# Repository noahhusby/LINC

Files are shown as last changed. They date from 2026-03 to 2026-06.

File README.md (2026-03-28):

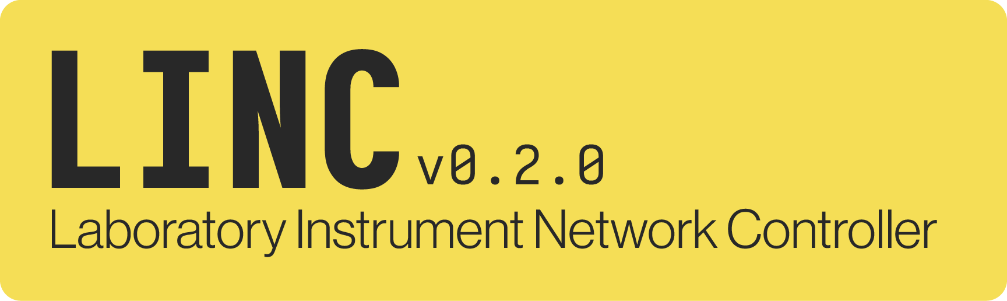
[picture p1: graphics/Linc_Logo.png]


## About

This project came about from the need to control my PM2812 dual-channel power supply manufactured by the Phillips and Fluke consortium in the mid 90s. While later revisions of this device did feature a serial port, the earlier versions (such as mine) were stuck with the GPIB/HP-IP interface. This interface was used on test equipment up until the mid 2010s and yet there is no simple or affordable way to communicate with it. The interface chips for GPIB are no longer manufactured and difficult to source. 

The goal of this project is to create a controller that can translate commands from a networked device (either over LAN or RS485) to the PM2812 power supply. This would allow for a desk-mounted control panel with a modern OLED display and tactile controls to replace the dated "system power supply-type" interface found on the PM2812.

## Features

- Console Control 💾
  - Virtual COM port allows direct control of test equipment over integrated USB-C port
- Modern Hardware 💻
  - Based upon STM32H533 using new level shifters instead of legacy/unavailable SN7515x series chips
- Remote Control Capability 🛜
  - Integrated RS485 port for secondary physical control panel 

## Related

- LeHuman/[PMPi](https://github.com/LeHuman/PMPi)
- mnemocron/[gpibusb-firmware-stm32](https://github.com/mnemocron/gpibusb-firmware-stm32)

## License

This project is licensed under the `CERN OHL-P-v2 License`.

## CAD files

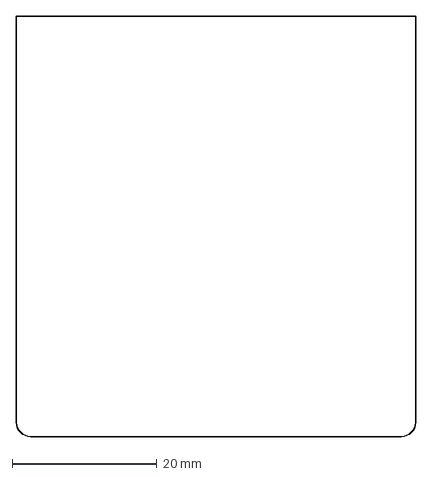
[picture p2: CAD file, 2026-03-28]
board_layout.dxf
55.1 x 58.0 mm

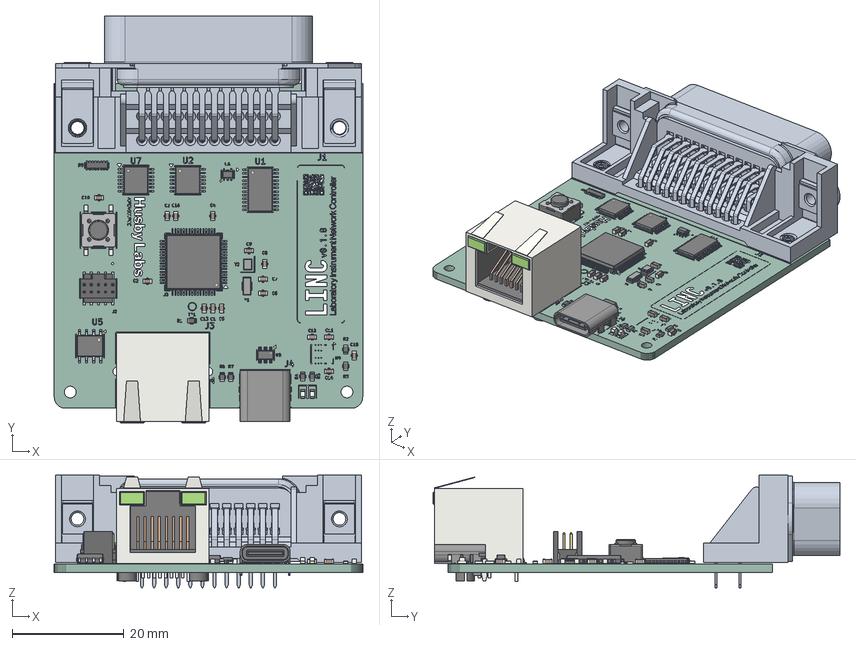
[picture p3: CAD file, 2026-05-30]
outputs/pcb/.step
55.1 x 72.7 x 20.1 mm
C_0603_1608Metric x 16
USB_C_Receptacle_GCT_USB4085
LQFP-64_10x10mm_P0.5mm
TSSOP-24_4.4x7.8mm_P0.65mm
SOIC-8_3.9x4.9mm_P1.27mm
LED_0603_1608Metric x 2
Crystal_SMD_2016-4Pin_2.0x1.6mm
TSSOP-14_4.4x5mm_P0.65mm x 2
R_0603_1608Metric x 7
SOT-23-6
112-024-113R001
SOT-353_SC-70-5
R_Array_Convex_8x0602
Crystal_SMD_3215-2Pin_3.2x1.5mm
RJ45_Amphenol_RJHSE538x
SW_SPST_PTS645Sx43SMTR92
FTSH-105-01-L-DV-K_body
FTSH-105-01-L-DV-K_pins1
FTSH-105-01-L-DV-K_pins2
LINC_silkscreen x 2
LINC_PCB

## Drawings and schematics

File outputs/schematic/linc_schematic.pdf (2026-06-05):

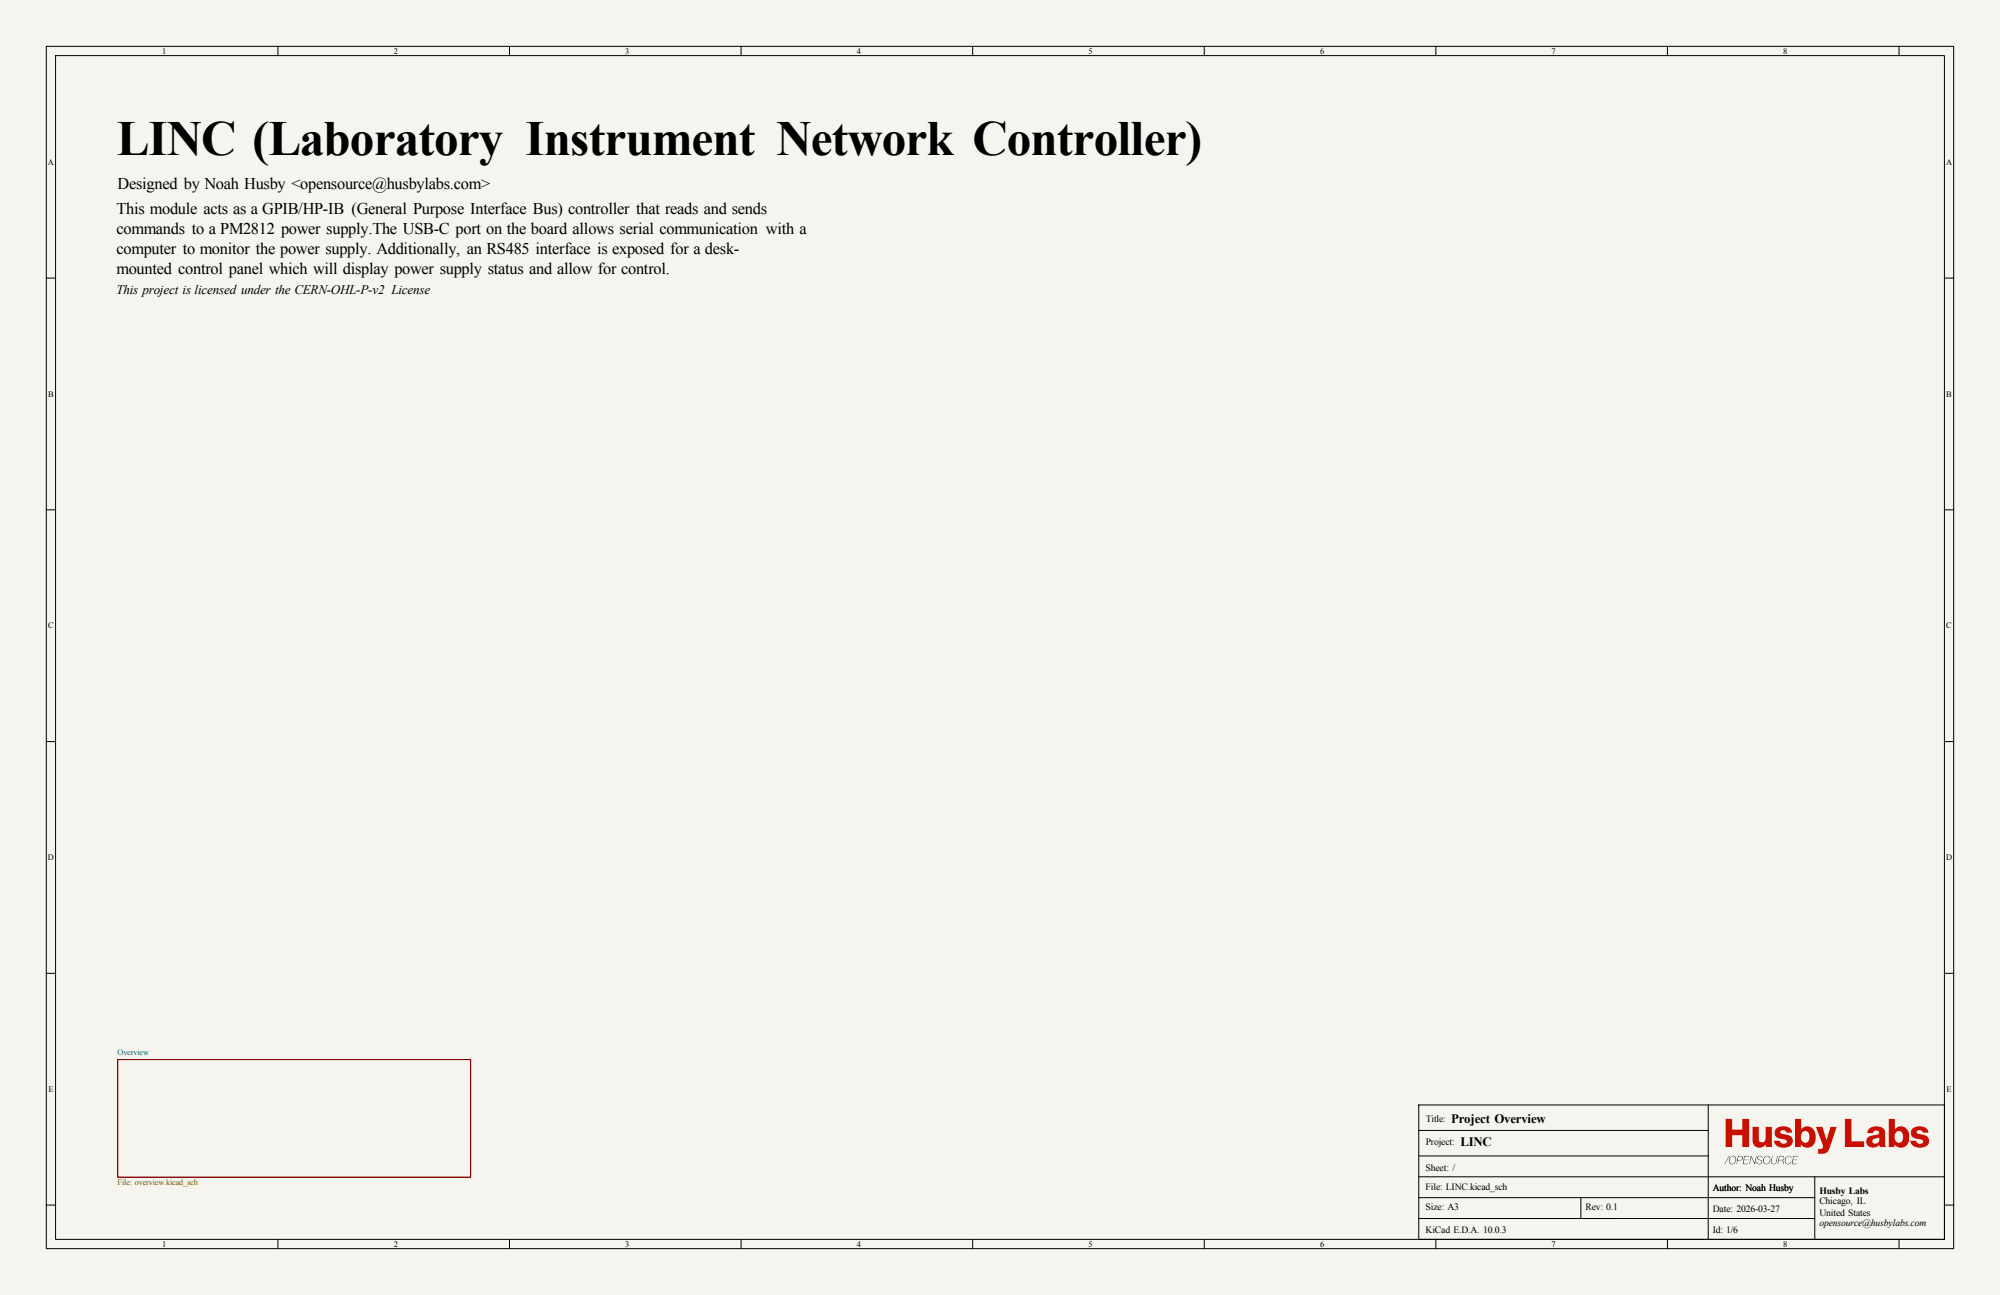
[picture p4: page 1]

LINC (Laboratory Instrument Network Controller)

Designed by Noah Husby <opensource@husbylabs.com>
This module acts as a GPIB/HP-IB (General Purpose Interface Bus) controller that reads and sends
commands to a PM2812 power supply.The USB-C port on the board allows serial communication with a
computer to monitor the power supply. Additionally, an RS485 interface is exposed for a desk-
mounted control panel which will display power supply status and allow for control.
This project is licensed under the CERN-OHL-P-v2 License

Id: 1/6 File: LINC.kicad_sch Sheet: / Project: LINC

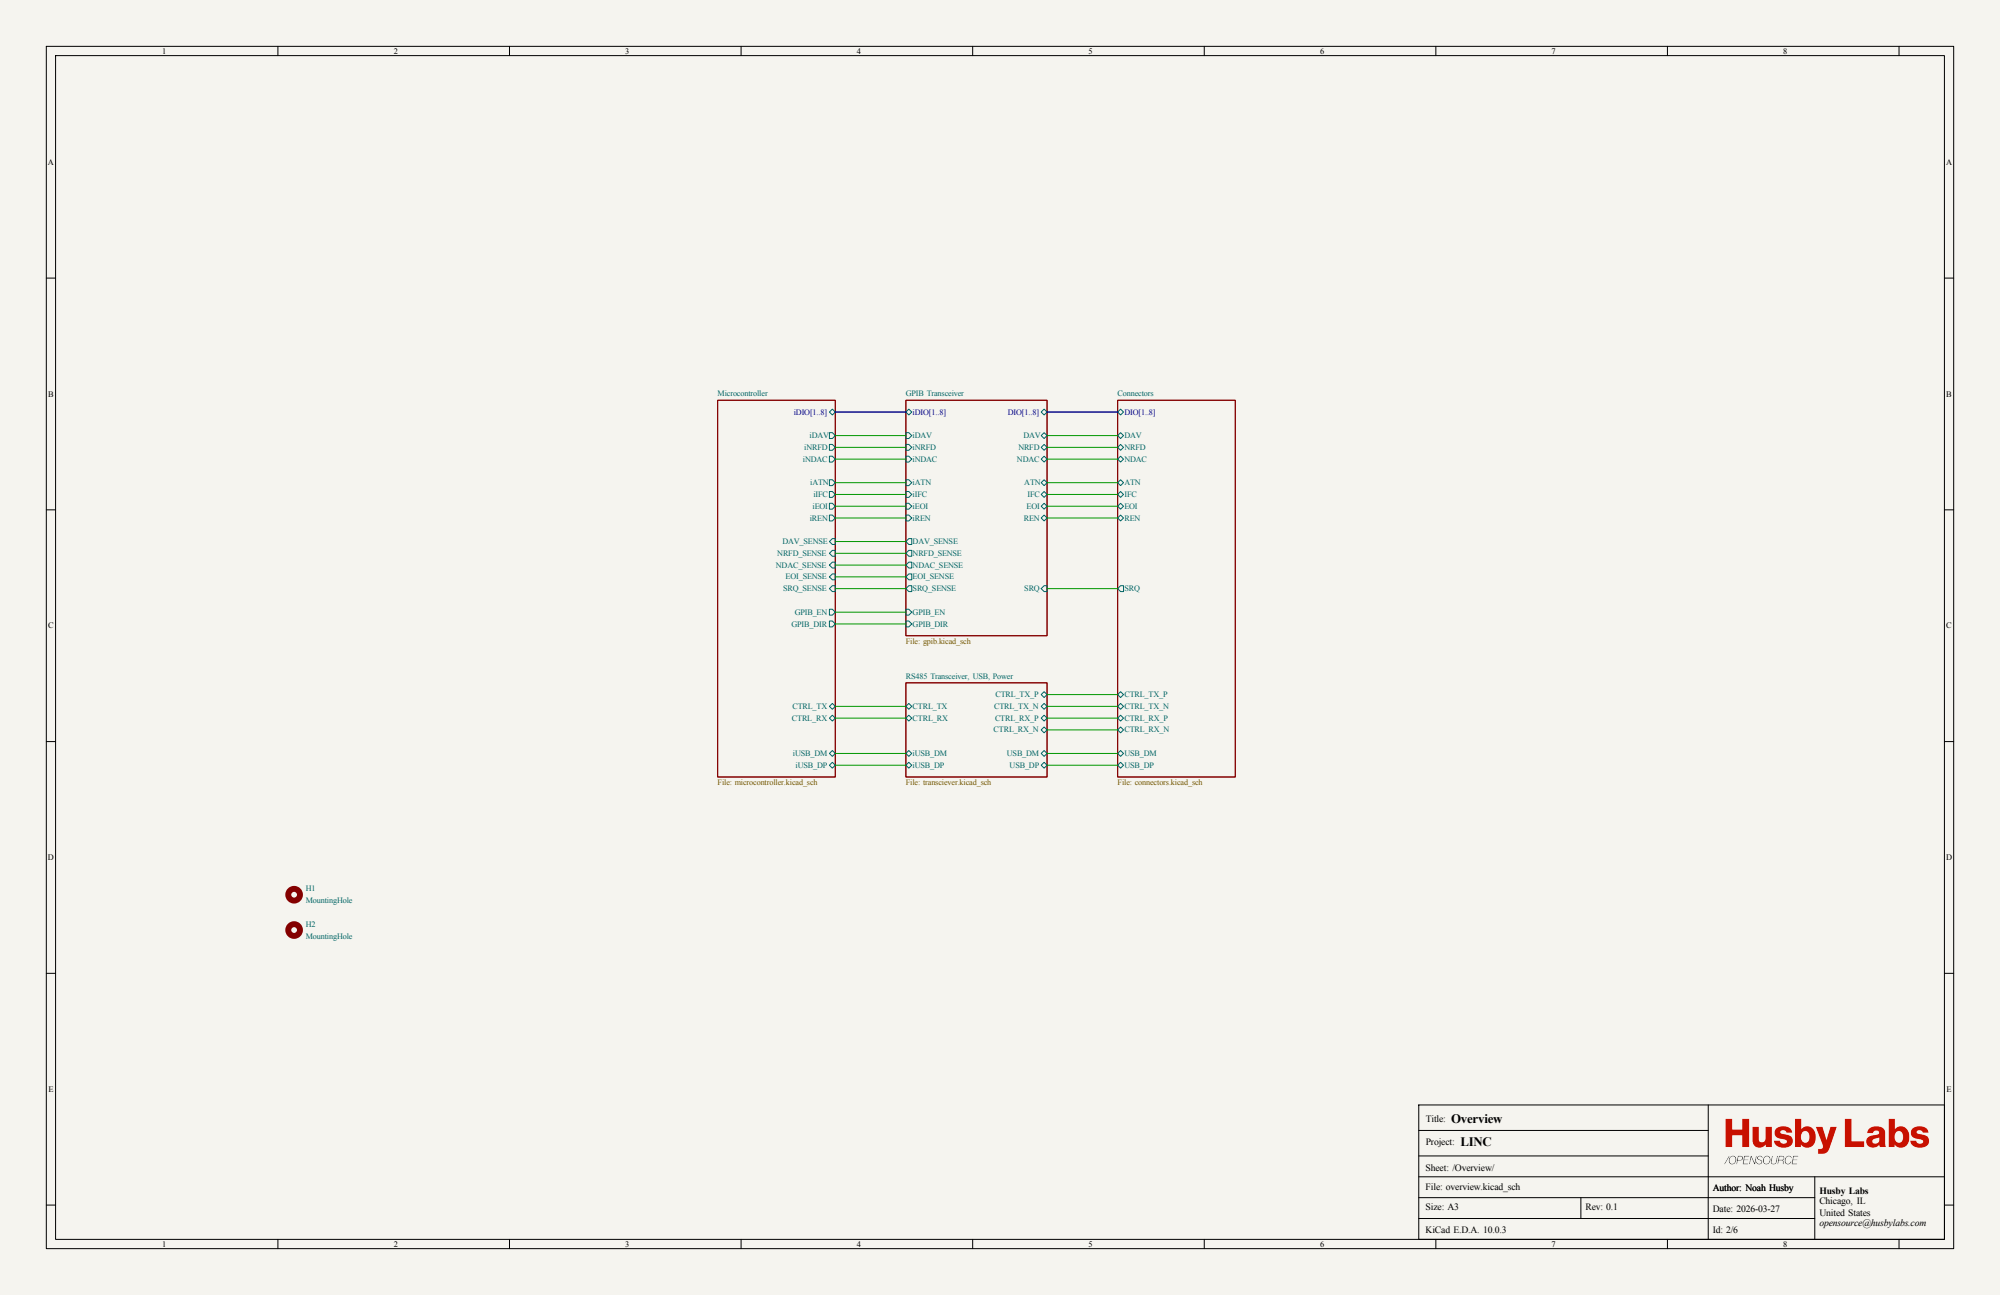
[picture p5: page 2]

iDIO[1..8] Microcontroller File: microcontroller.kicad_sch

USB_DP DIO[1..8] Connectors File: connectors.kicad_sch

iUSB_DP RS485 Transceiver, USB, Power File: transciever.kicad_sch H2 MountingHole H1 MountingHole

Id: 2/6 File: overview.kicad_sch Sheet: /Overview/ Project: LINC

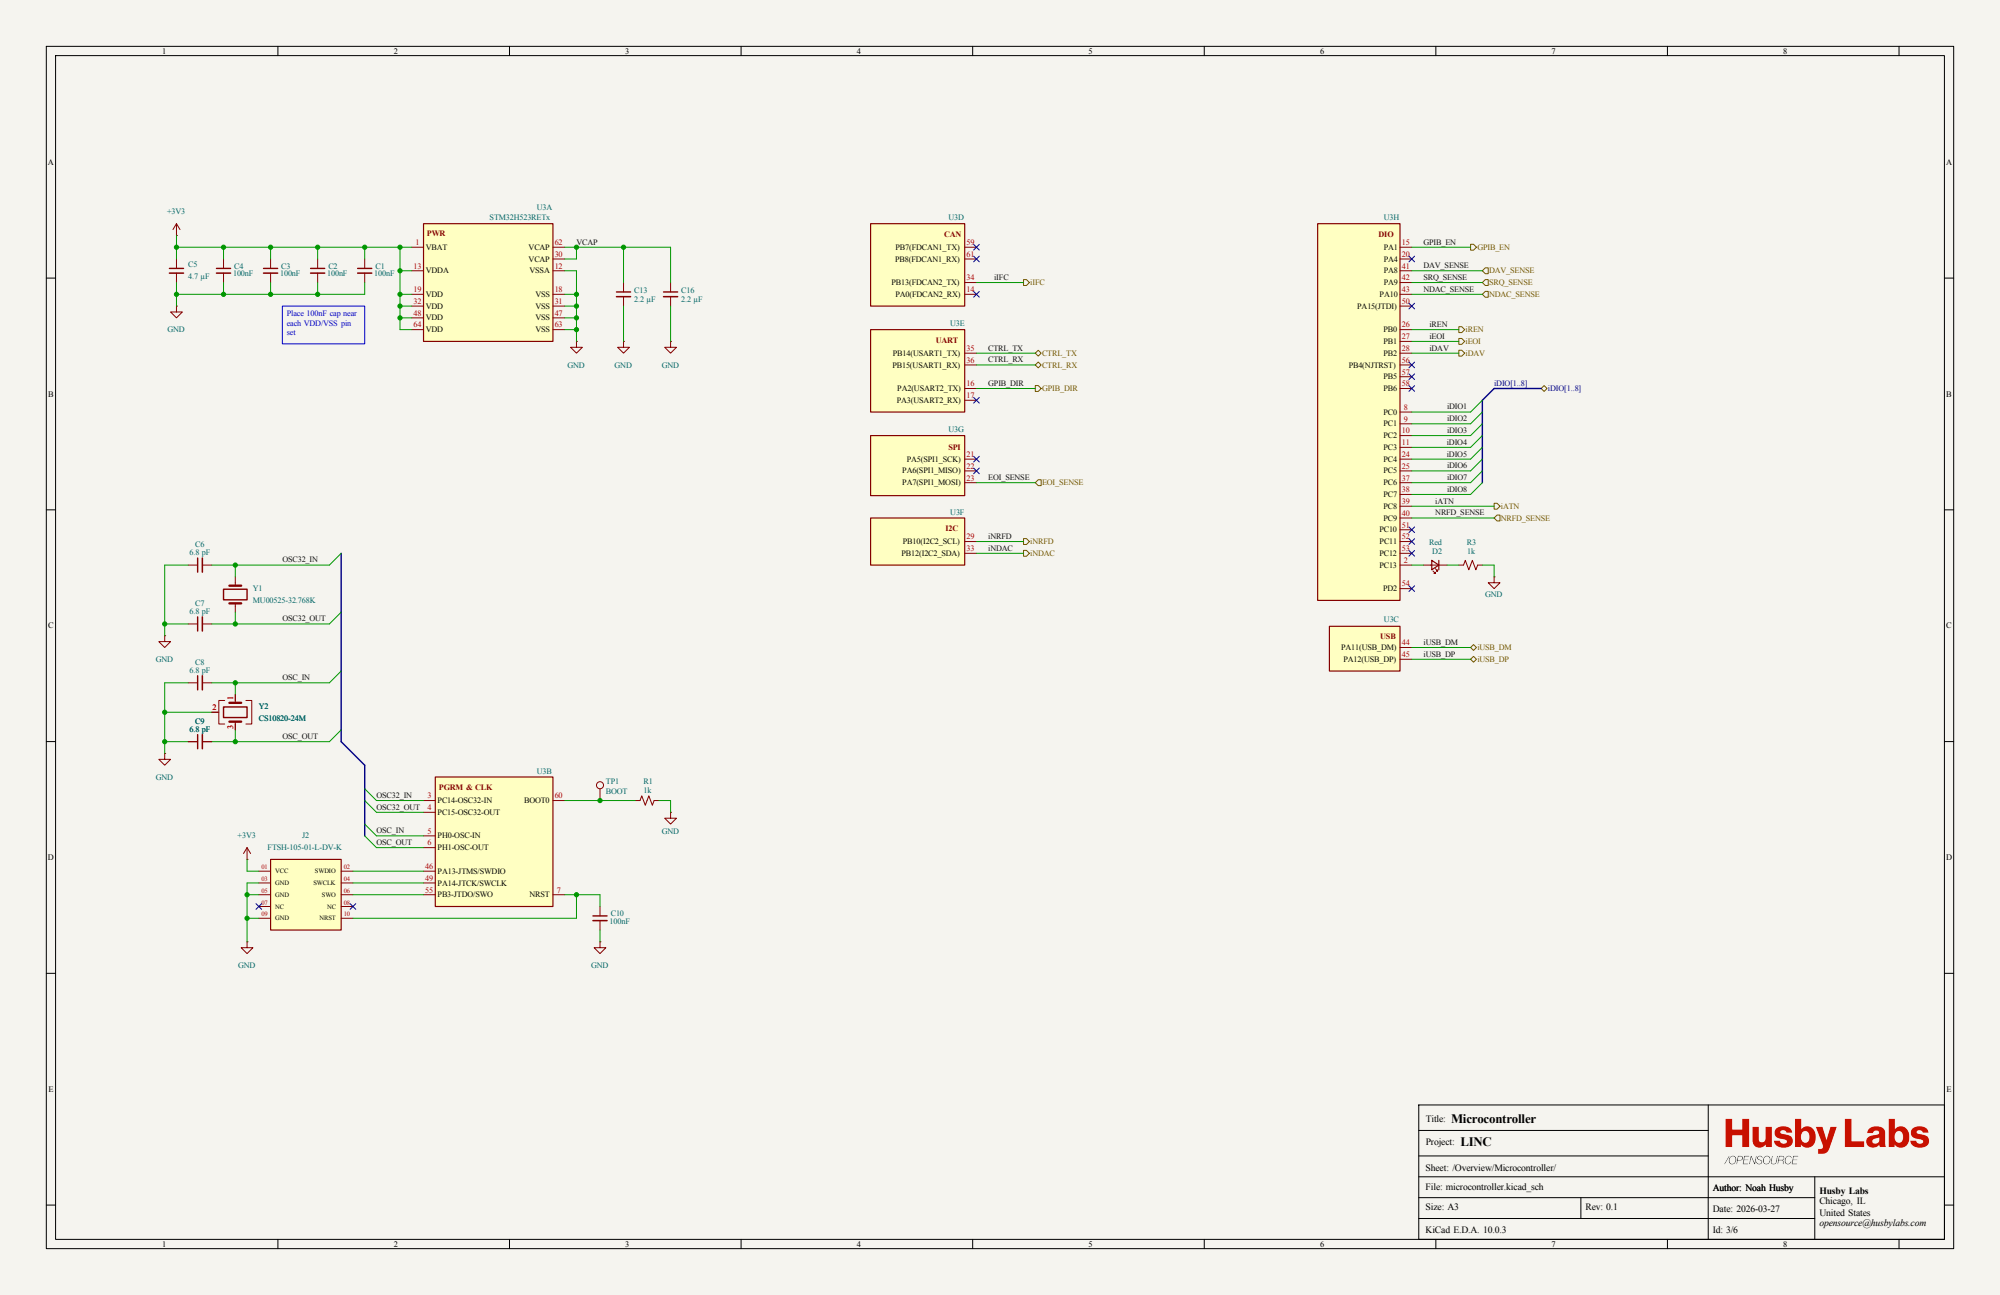
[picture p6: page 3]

Place 100nF cap near each VDD/VSS pin

Id: 3/6 File: microcontroller.kicad_sch Sheet: /Overview/Microcontroller/ Project: LINC

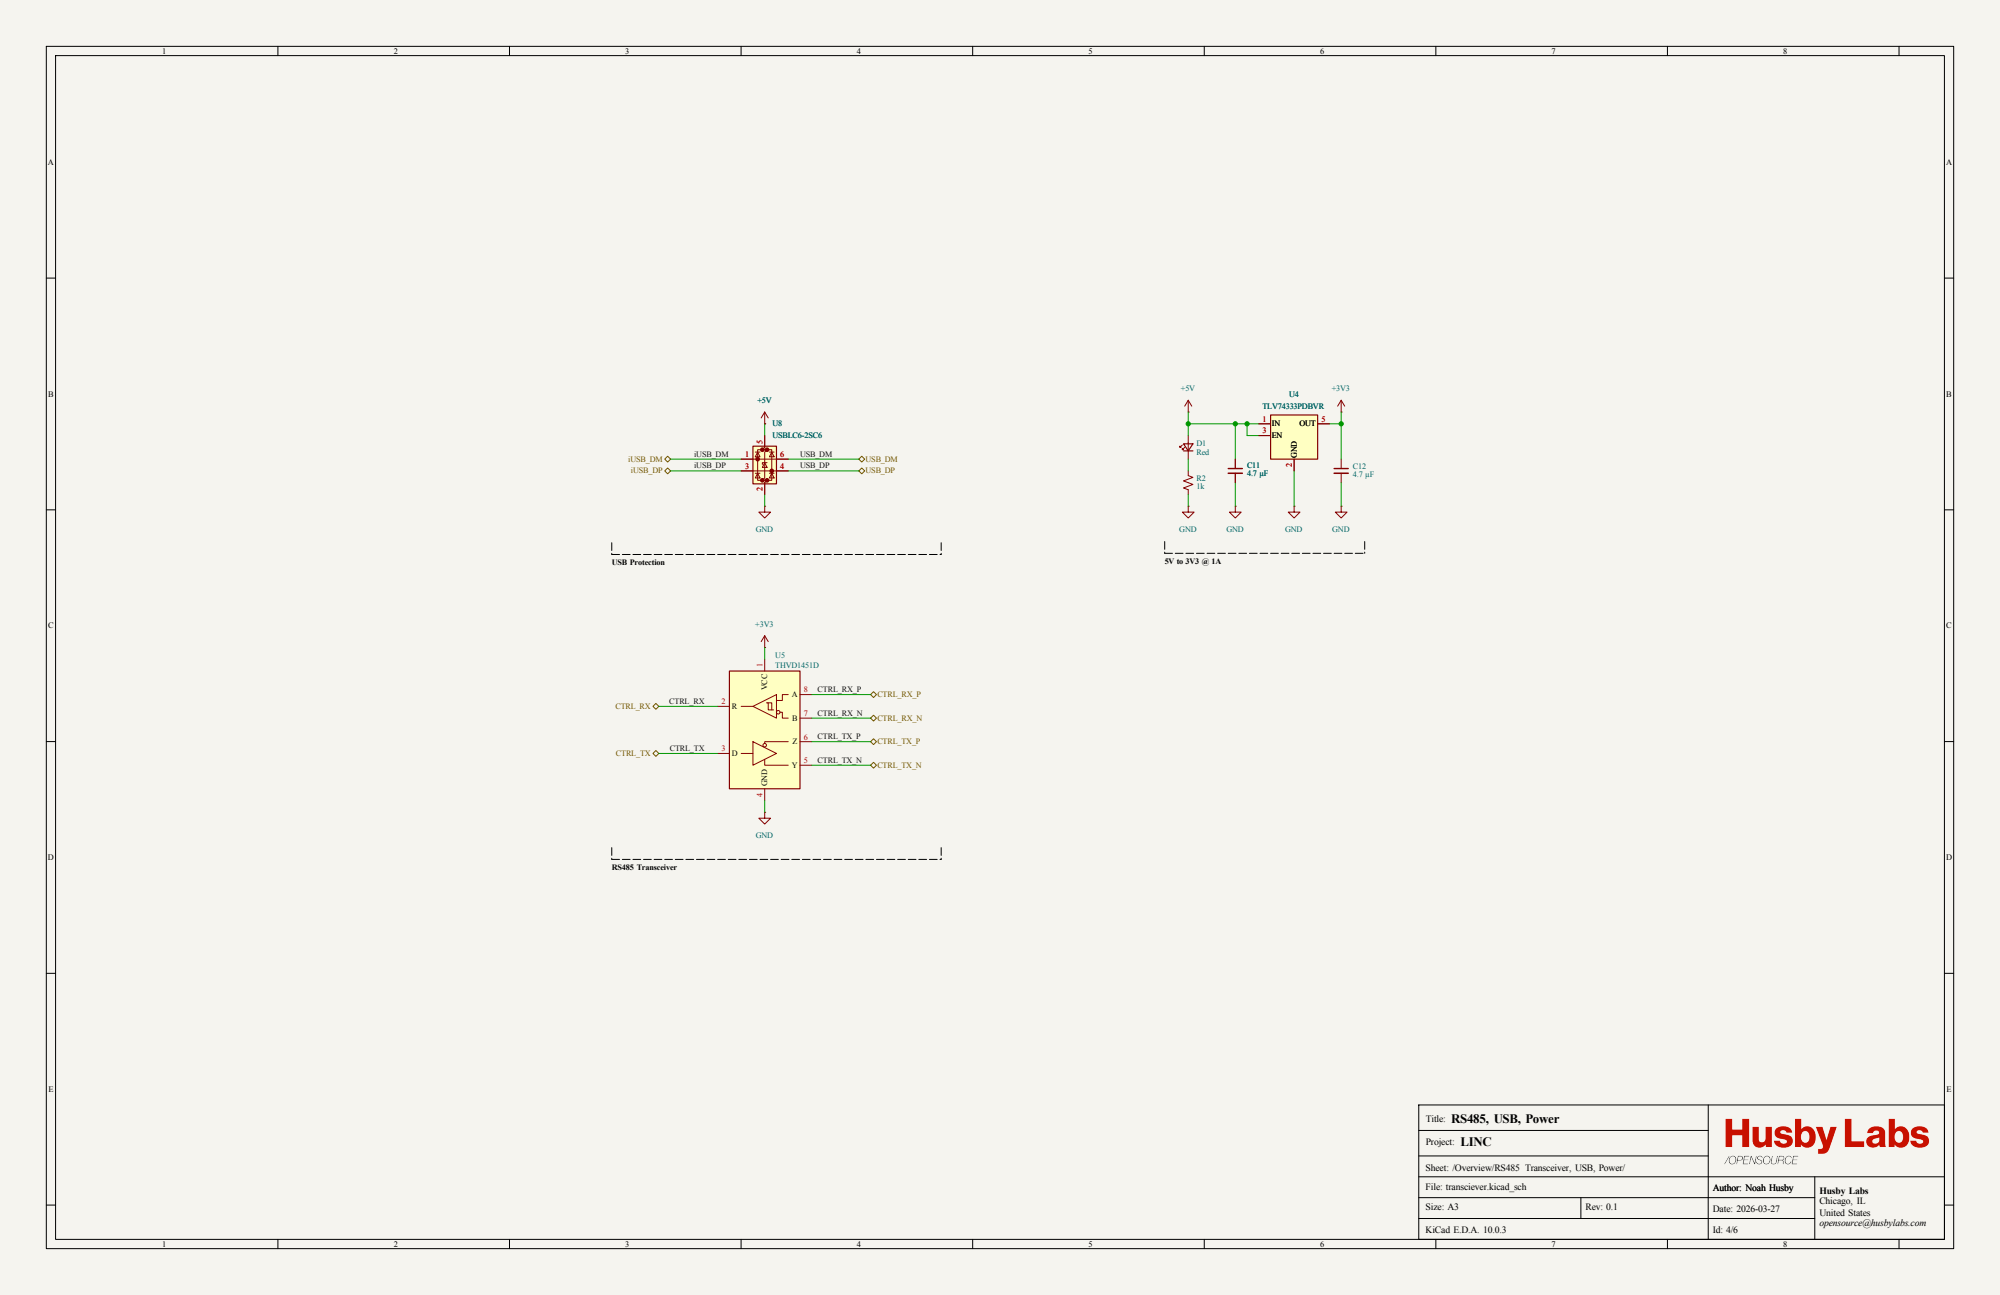
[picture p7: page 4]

Id: 4/6 File: transciever.kicad_sch Sheet: /Overview/RS485 Transceiver, USB, Power/ Project: LINC

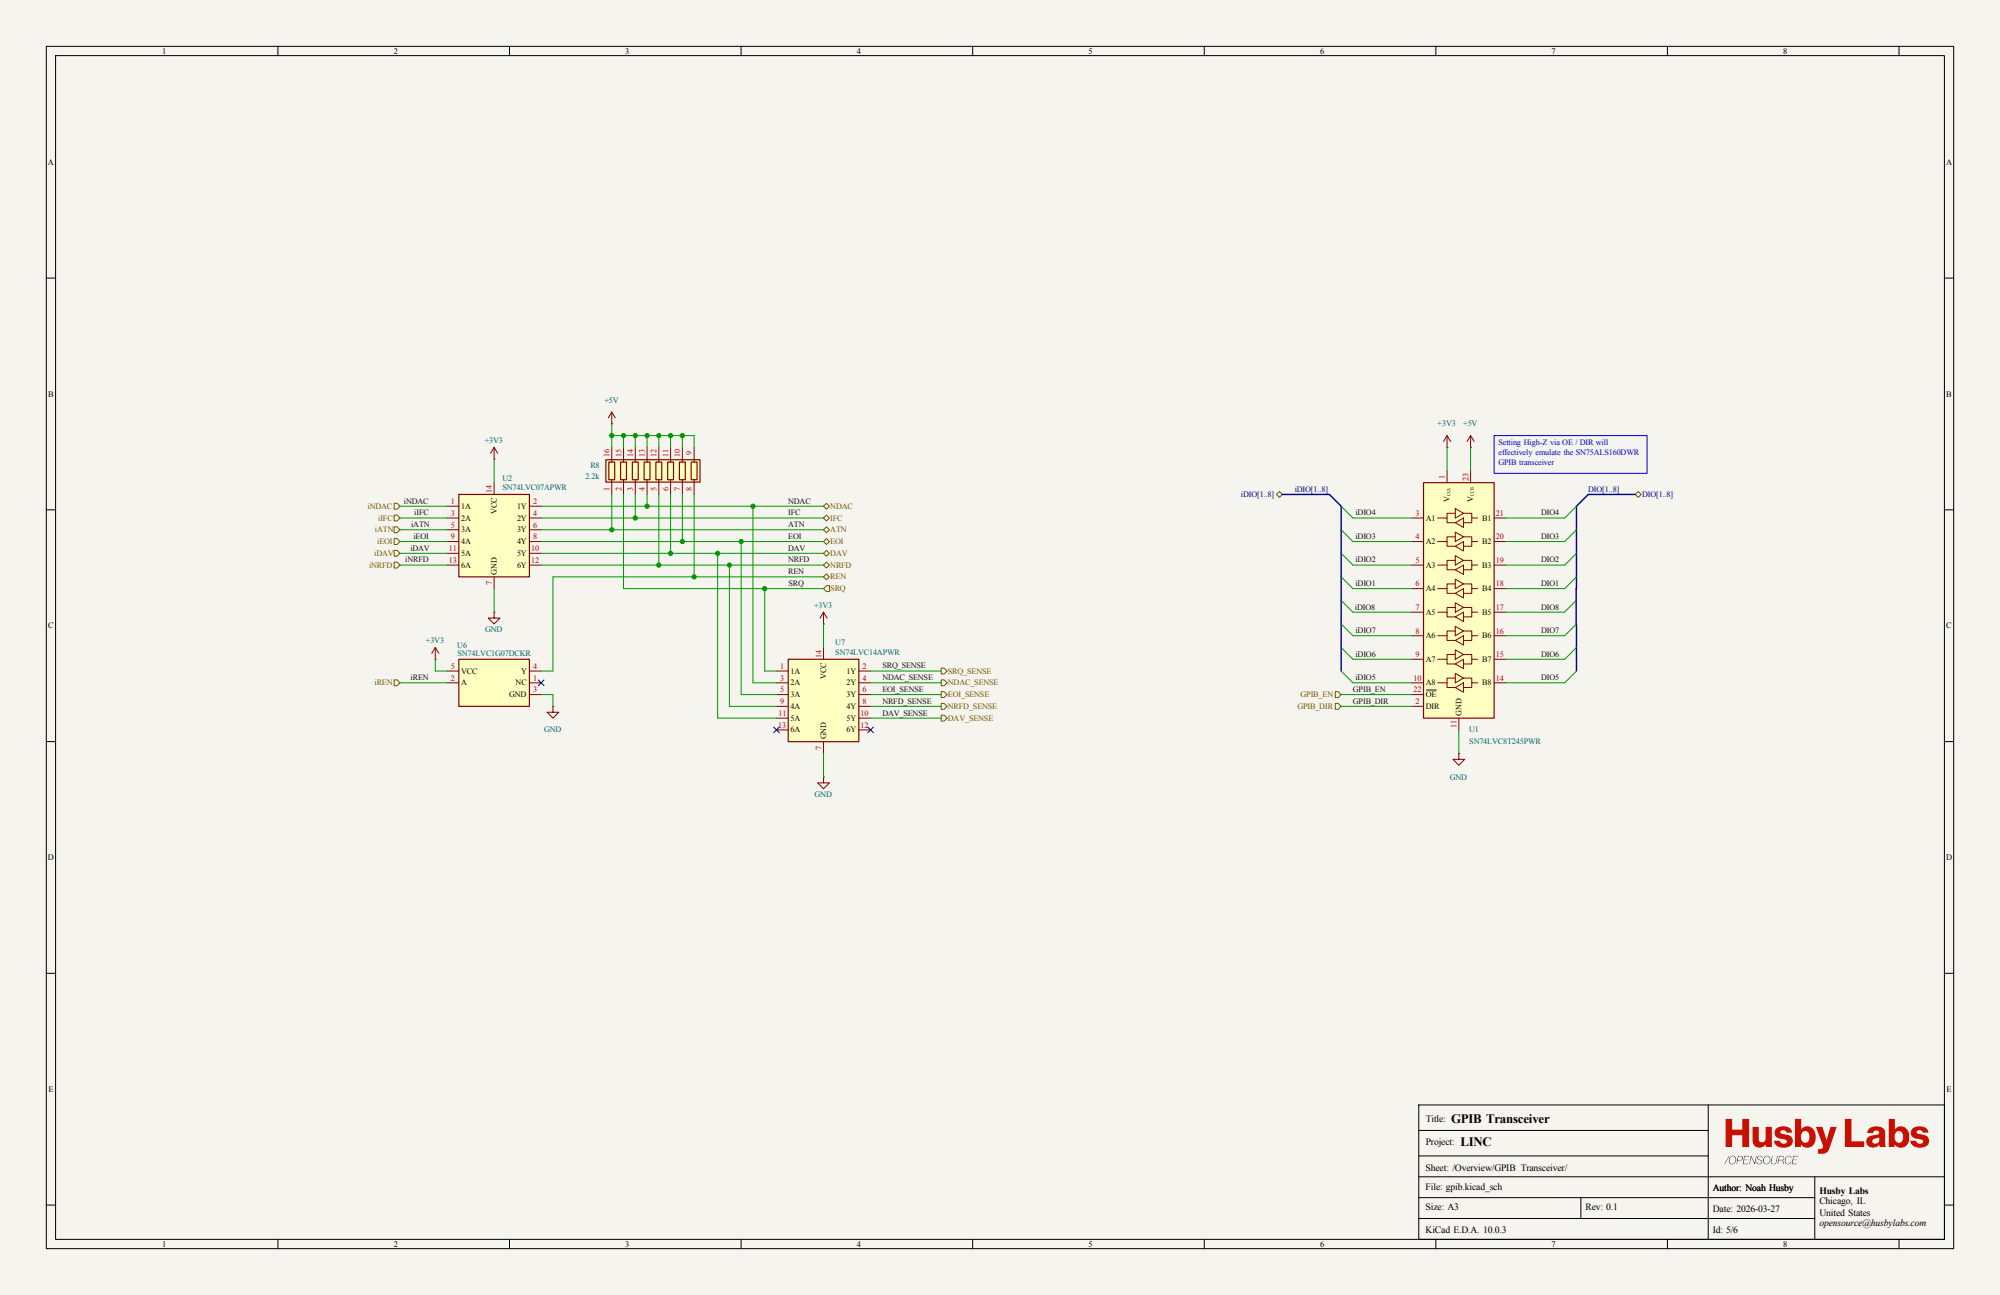
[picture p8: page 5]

VCCA 1 DIR 2 A1 3 A2 4 A3 5 A4 6 A5 7 A6 8 A7 9 A8 10 GND 11 B8 14 B7 15 B6 16 B5 17 B4 18 B3 19 B2 20 B1 21 OE 22 VCCB 23 U1 SN74LVC8T245PWR GND

Id: 5/6 File: gpib.kicad_sch Sheet: /Overview/GPIB Transceiver/ Project: LINC

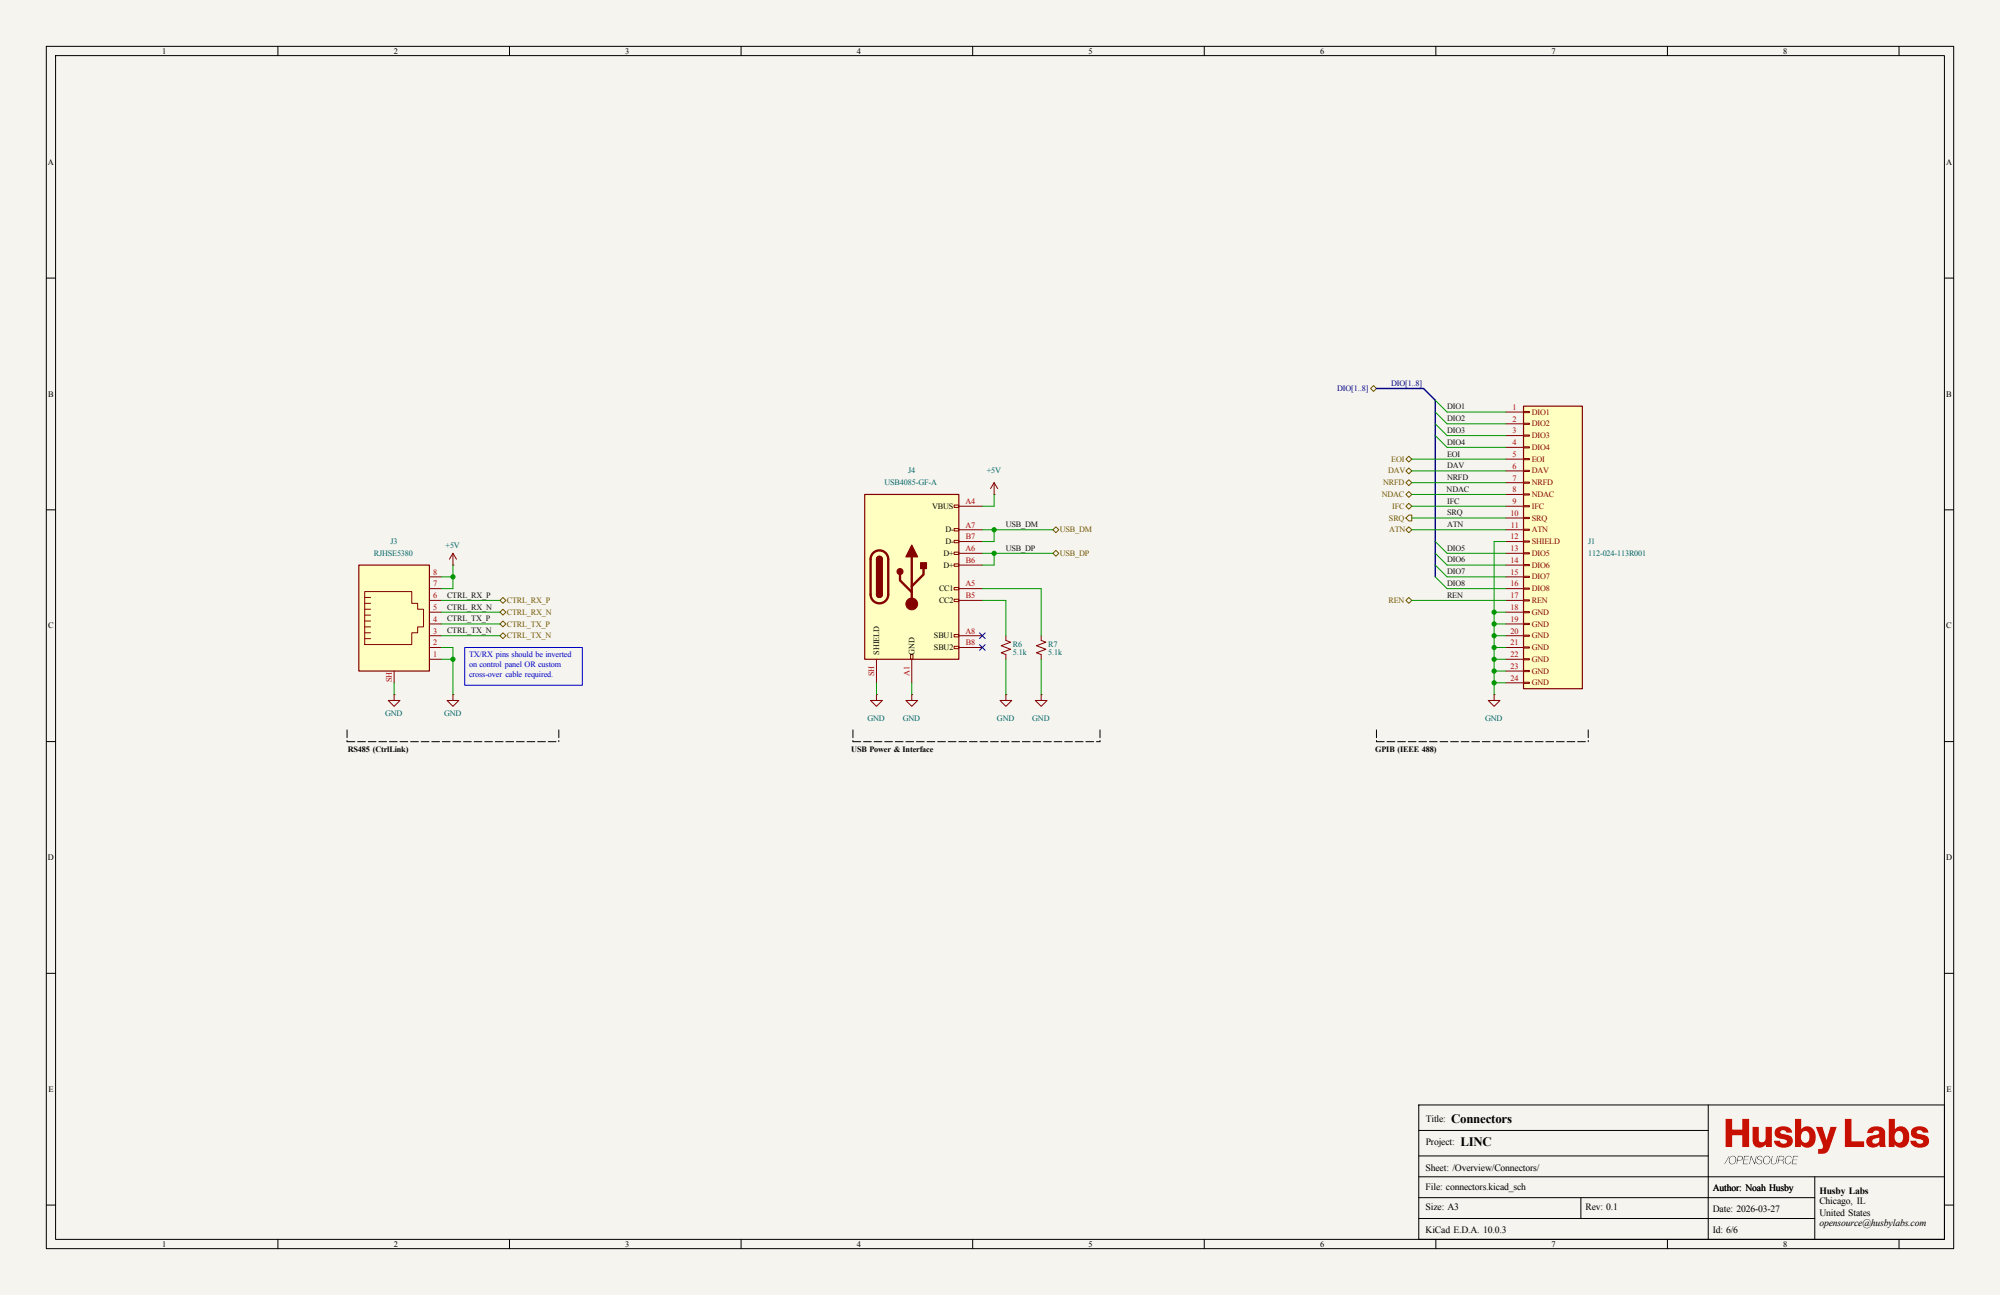
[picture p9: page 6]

TX/RX pins should be inverted
on control panel OR custom

Id: 6/6 File: connectors.kicad_sch Sheet: /Overview/Connectors/ Project: LINC

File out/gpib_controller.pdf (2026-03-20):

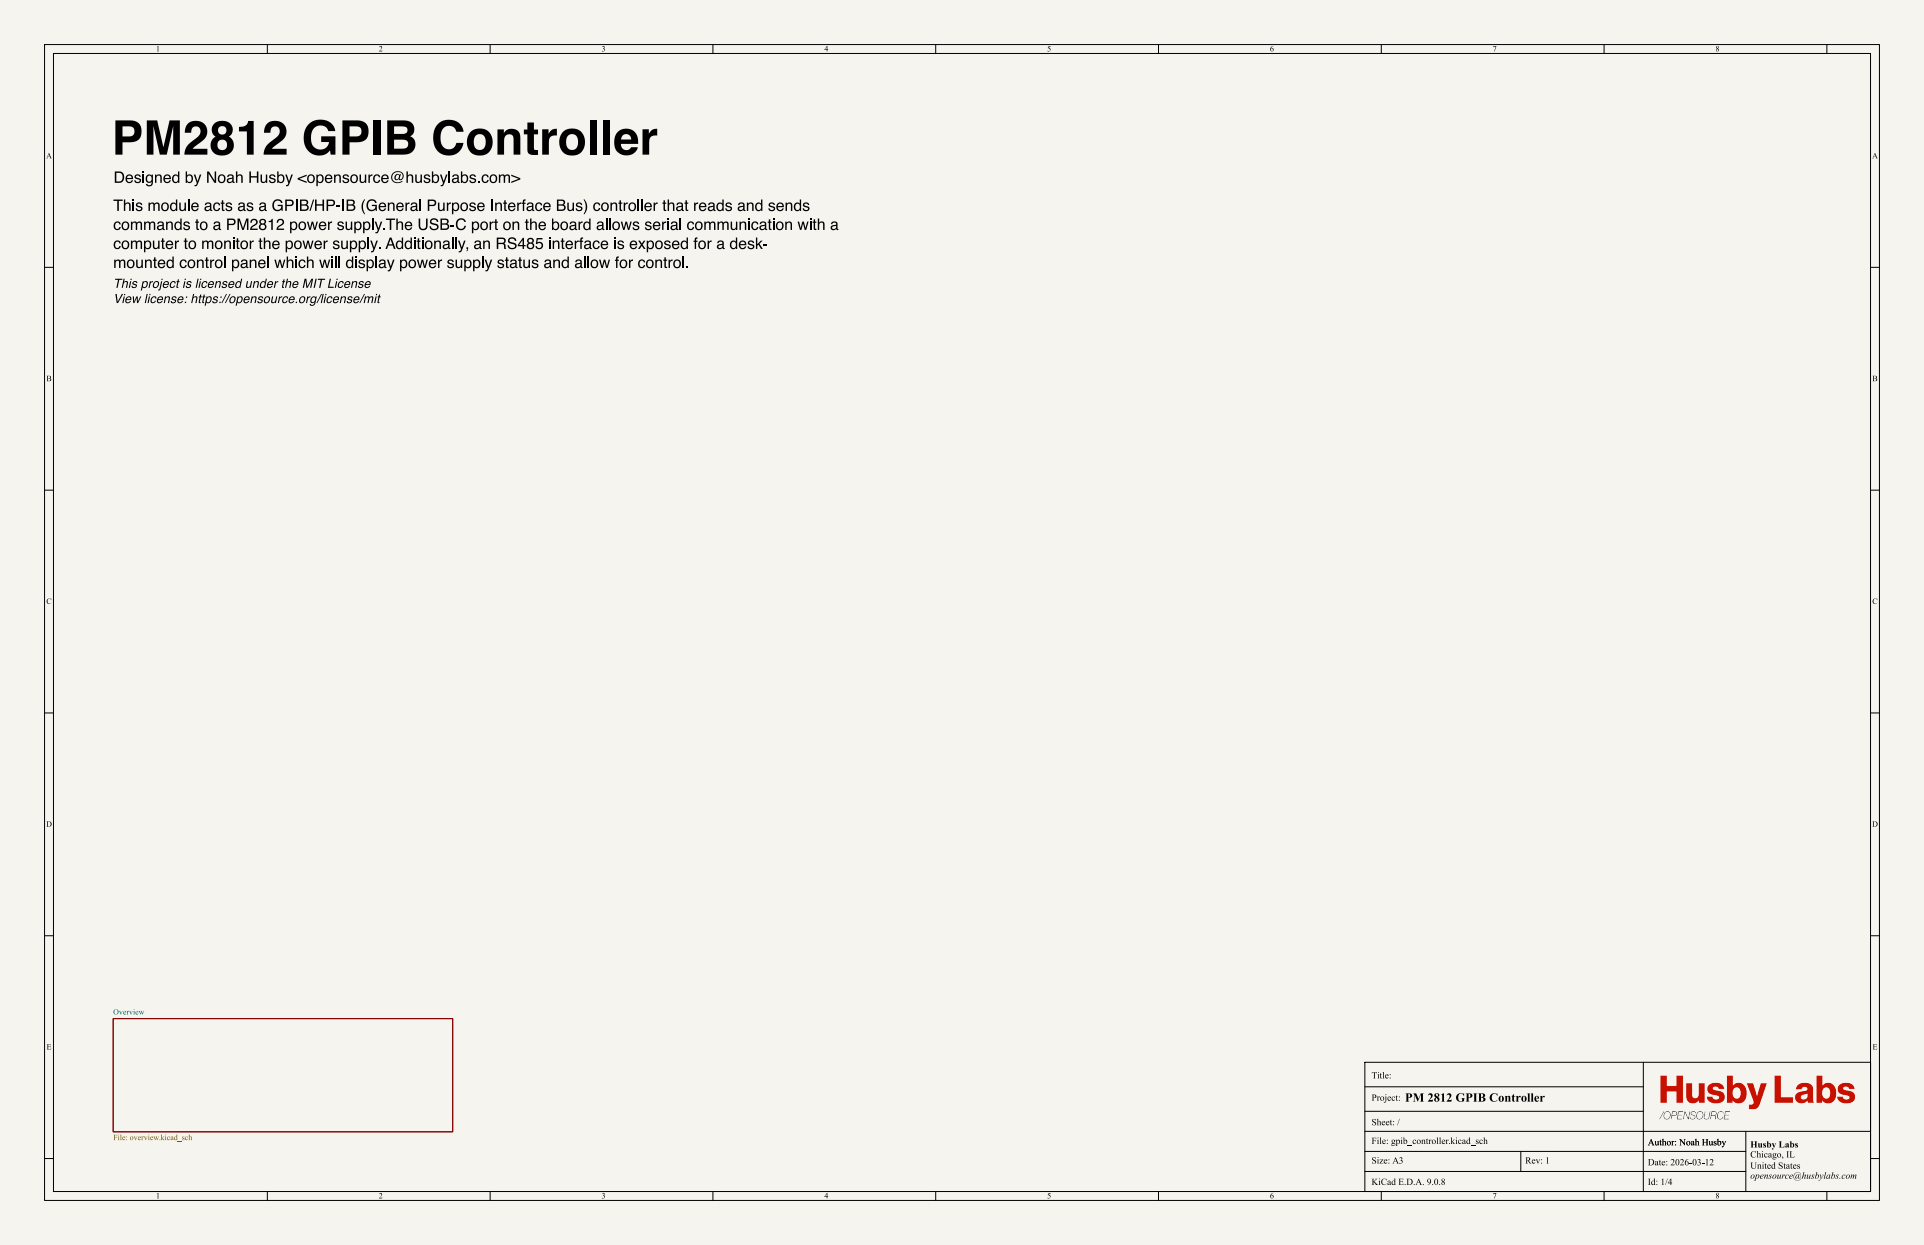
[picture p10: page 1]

Designed by Noah Husby <opensource@husbylabs.com>
This module acts as a GPIB/HP-IB (General Purpose Interface Bus) controller that reads and sends
commands to a PM2812 power supply.The USB-C port on the board allows serial communication with a
computer to monitor the power supply. Additionally, an RS485 interface is exposed for a desk-
mounted control panel which will display power supply status and allow for control.
This project is licensed under the MIT License
View license: https://opensource.org/license/mit

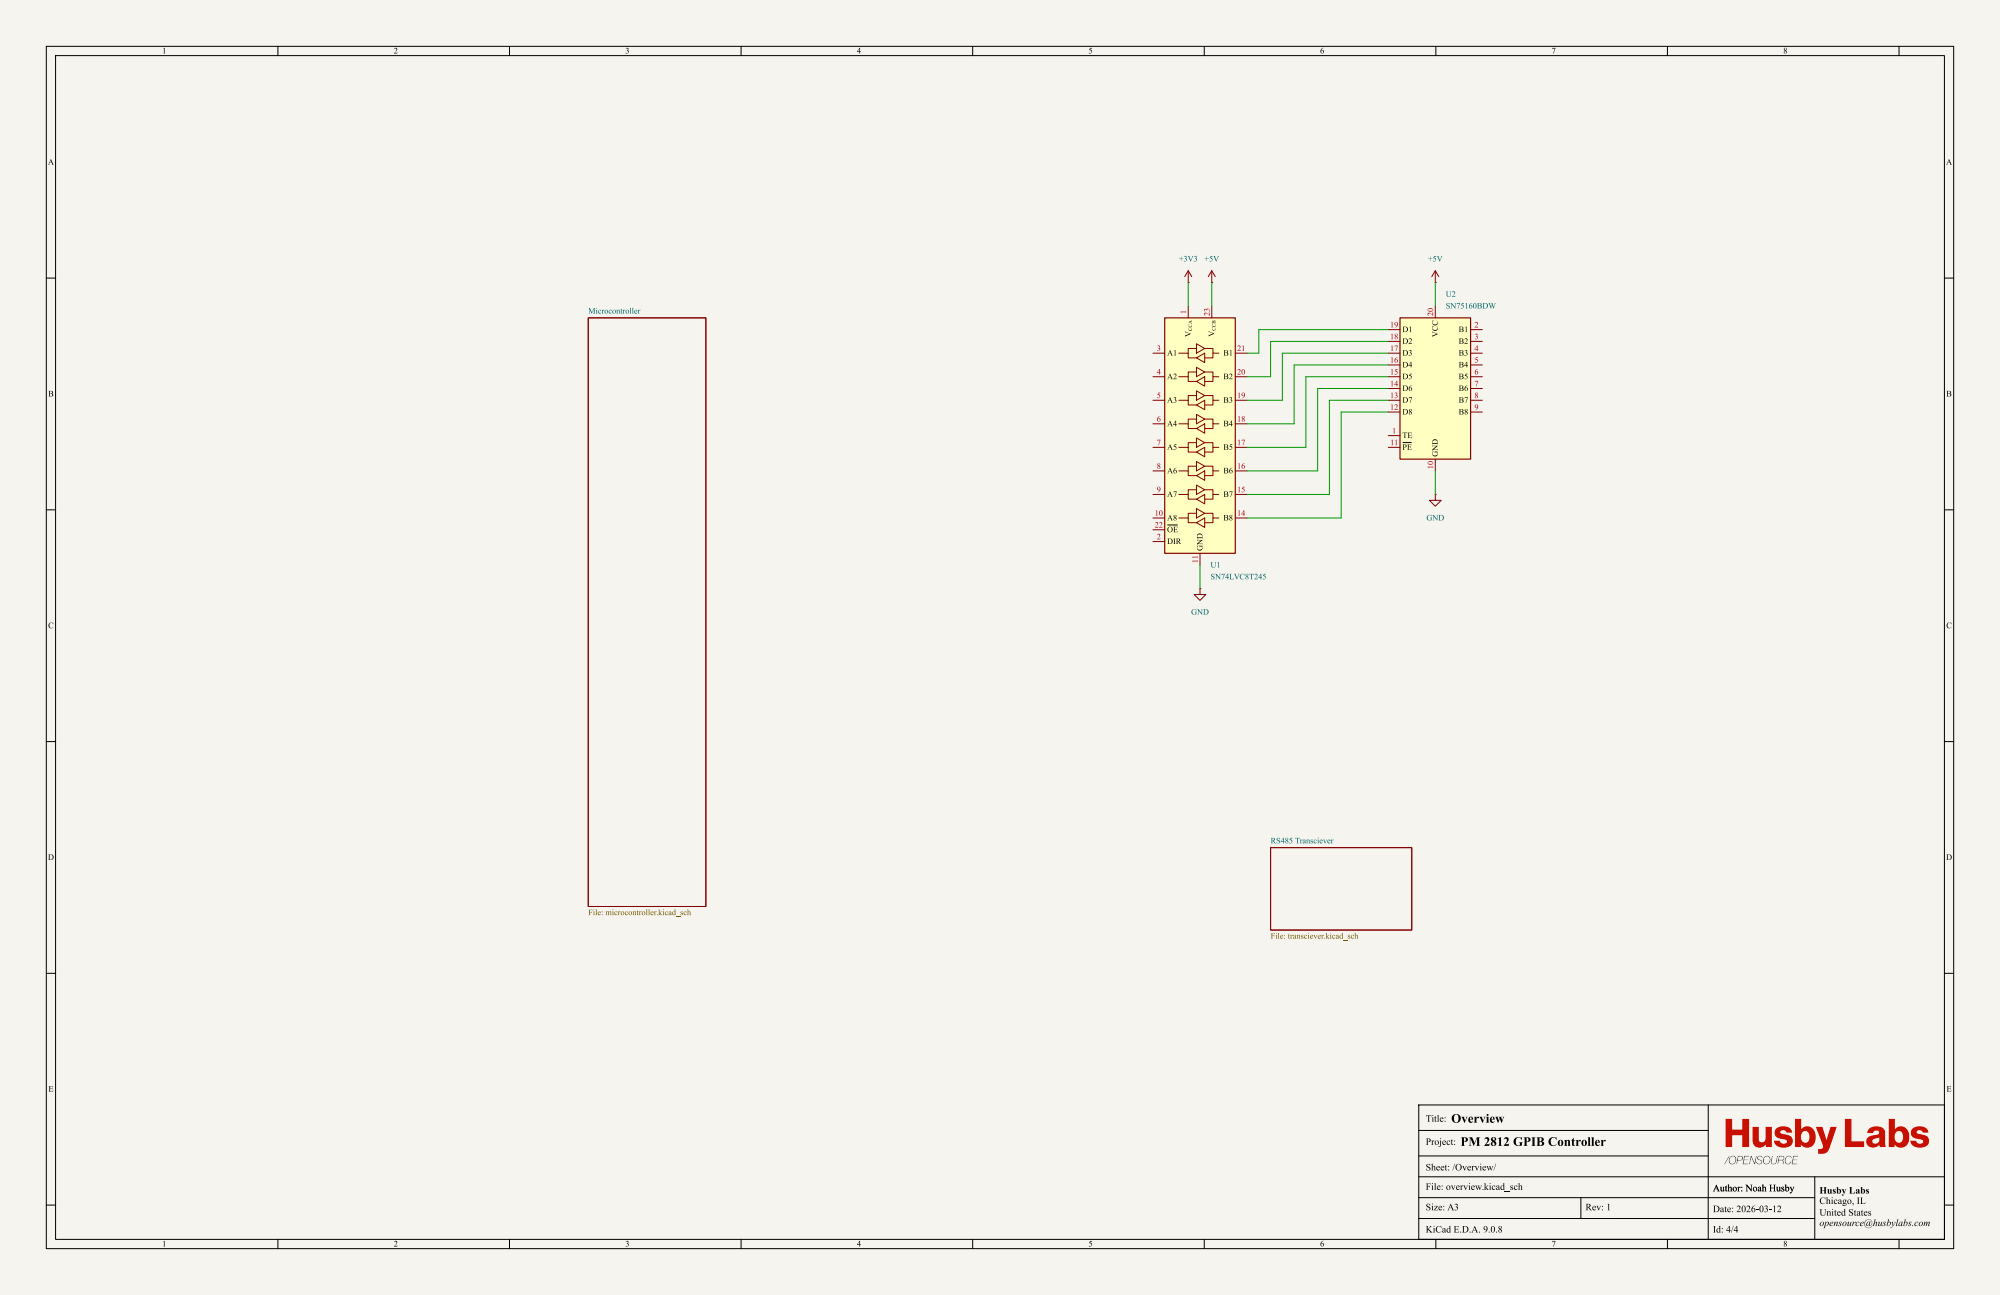
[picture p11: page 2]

Id: 4/4 File: overview.kicad_sch Sheet:/Overview/ Project:PM 2812GPIB Controller Title: Overview

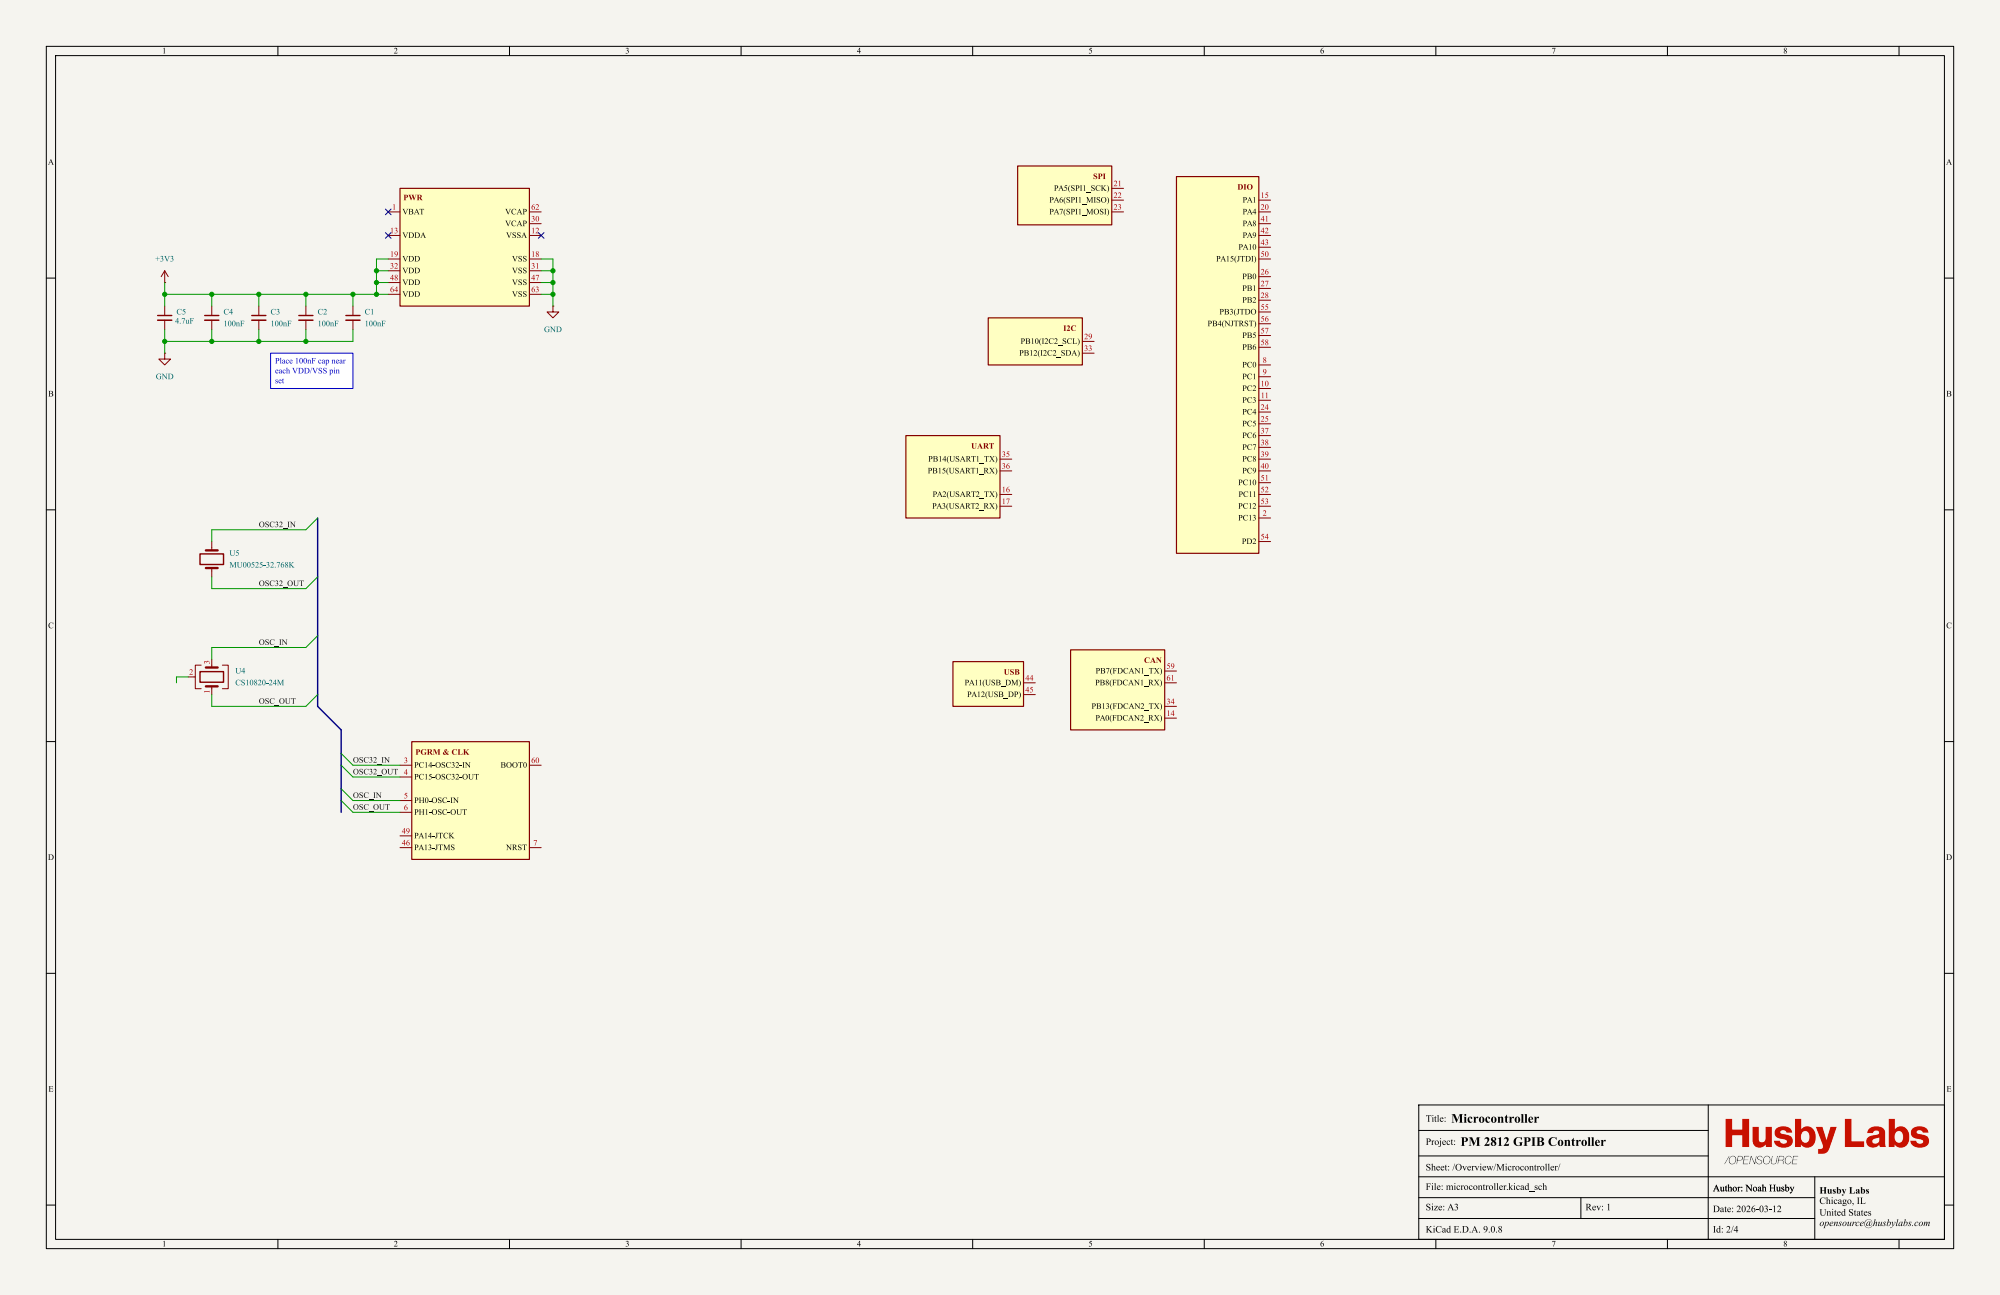
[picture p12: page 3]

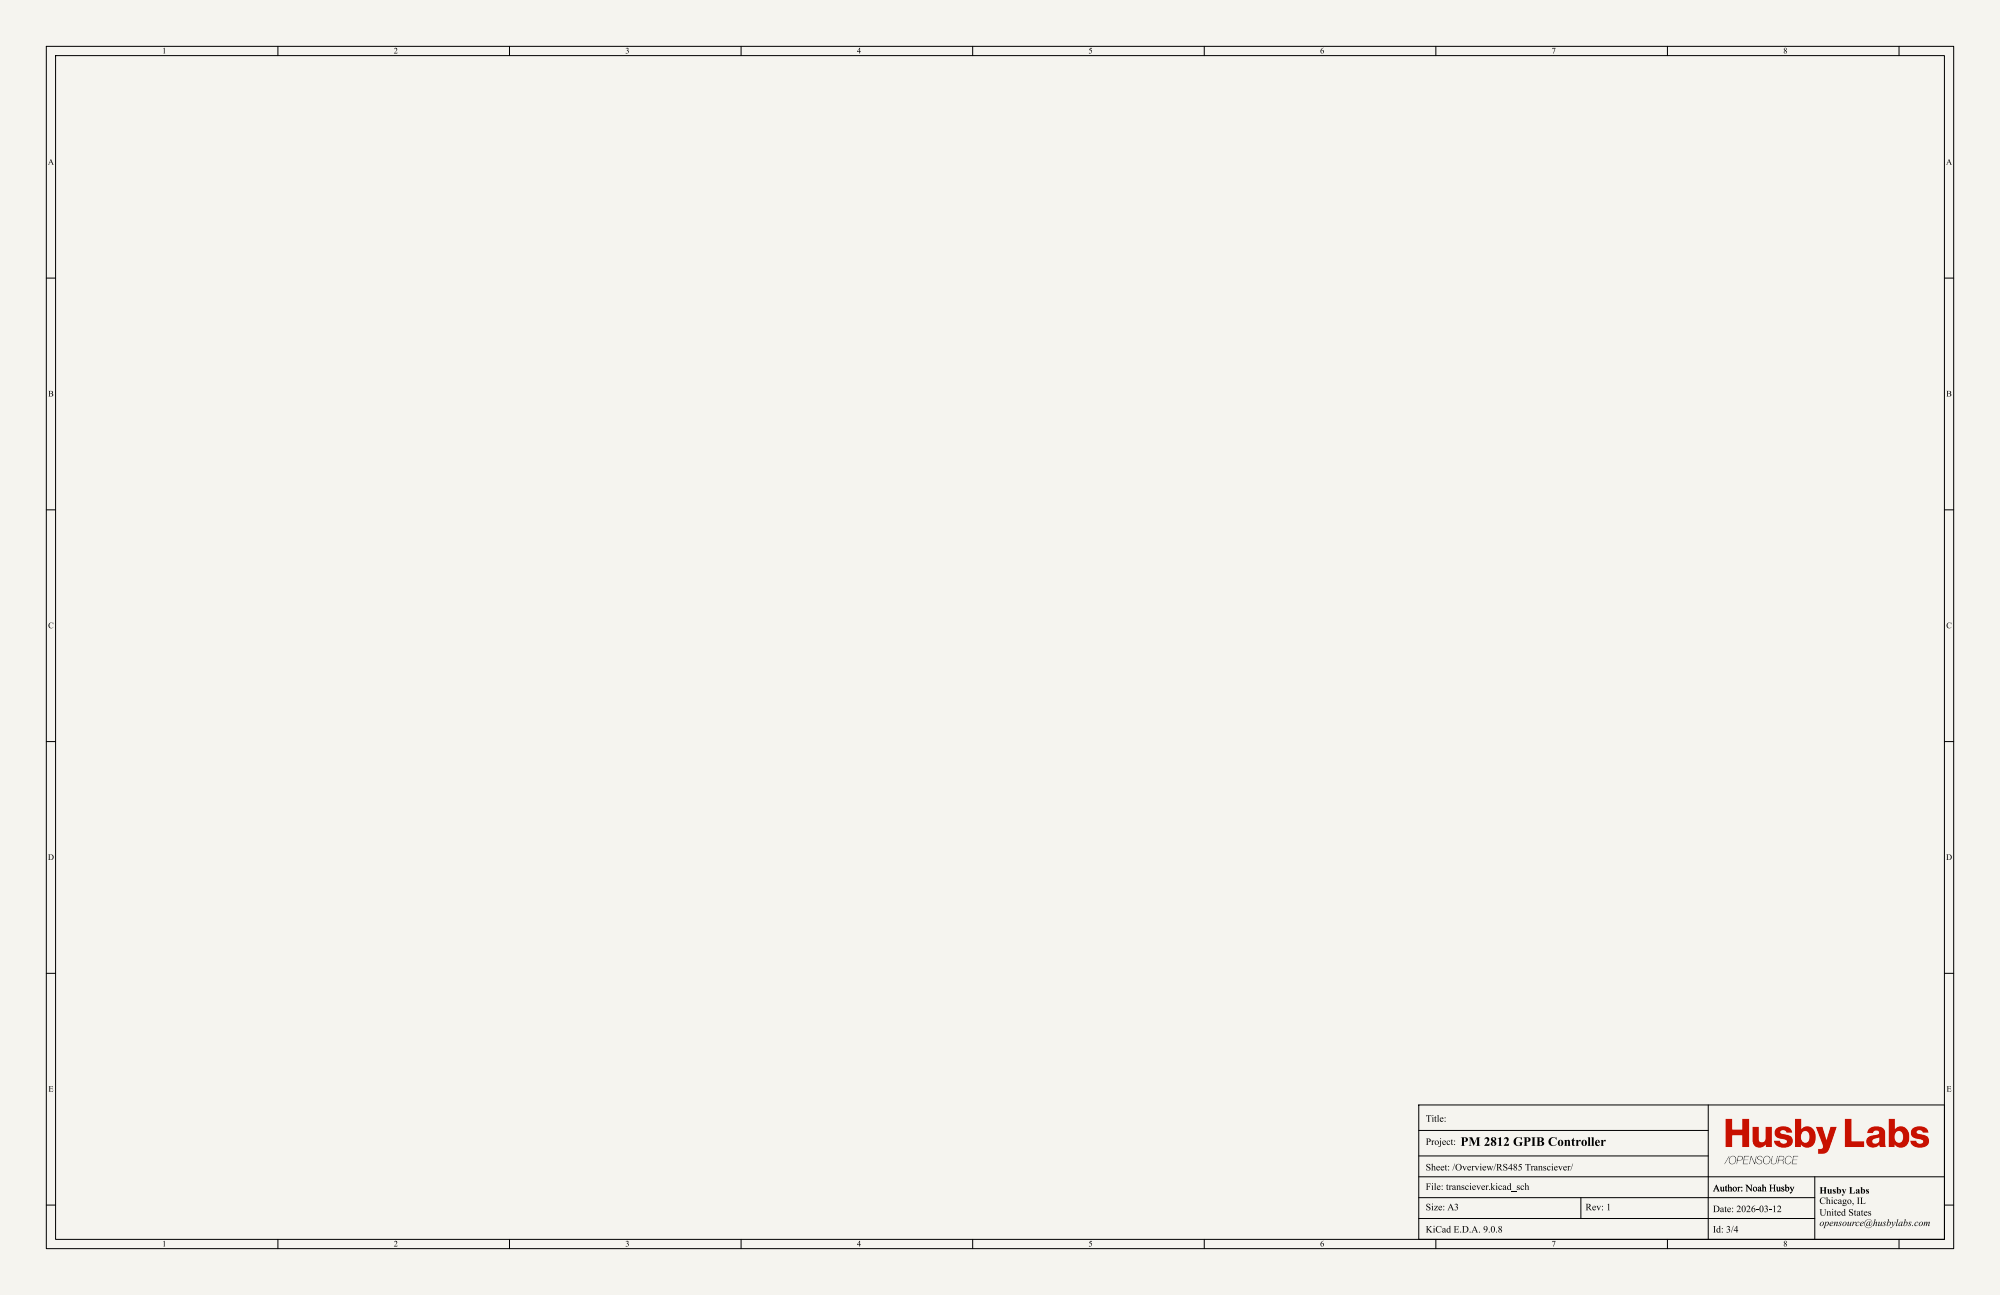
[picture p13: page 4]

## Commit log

2026-03-12 inital commit
    [gpib_controller.kicad_pcb, gpib_controller.kicad_sch, microcontroller.kicad_sch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]
2026-03-13 Updated title block and structure
    [gpib_controller.kicad_pcb, gpib_controller.kicad_sch, microcontroller.kicad_sch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]
2026-03-13 Move to main directory
    [gpib_controller.kicad_pcb, gpib_controller.kicad_sch, microcontroller.kicad_sch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]
2026-03-20 Pre Ki10 migration
    [gpib_controller.kicad_pcb, microcontroller.kicad_sch, overview.kicad_sch]
2026-03-20 KiCad V10 migration
    [gpib_controller.kicad_pcb, gpib_controller.kicad_sch, microcontroller.kicad_sch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]
2026-03-21 Add connectors and GPIB sub-sheets
    [connectors.kicad_sch, gpib.kicad_sch, microcontroller.kicad_sch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]
2026-03-21 Add RS485 transciever
    [connectors.kicad_sch, transciever.kicad_sch]
2026-03-21 Add GPIB and RS485 (CtrlLink) ports
    [connectors.kicad_sch, gpib.kicad_sch]
2026-03-23 Update PCB
    [gpib_controller.kicad_pcb]
2026-03-23 Remove GPIB transcievers. Targeting modern replacements
    [gpib.kicad_sch, gpib_controller.kicad_pcb, microcontroller.kicad_sch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]
2026-03-23 Changed DIO transciever to TSSOP-24
    [gpib.kicad_sch, gpib_controller.kicad_pcb]
2026-03-23 Link DIO nets to GPIB connector
    [connectors.kicad_sch, gpib.kicad_sch, gpib_controller.kicad_pcb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]
2026-03-23 Added open-drain driver for GPIB control pins
    [connectors.kicad_sch, gpib.kicad_sch, gpib_controller.kicad_pcb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]
2026-03-23 Add Schmitt-Trig sense IC, connect GPIB conn nets and run jobfile
    [connectors.kicad_sch, gpib.kicad_sch, gpib_controller.kicad_pcb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]
2026-03-23 Add GPIB interface
    [connectors.kicad_sch, gpib.kicad_sch, overview.kicad_sch]
2026-03-24 Add power supply and USB protection
    [connectors.kicad_sch, gpib_controller.kicad_pcb, microcontroller.kicad_sch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]
2026-03-24 Finish up schematics
    [connectors.kicad_sch, gpib.kicad_sch, microcontroller.kicad_sch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]
2026-03-25 Start work on PCB
    [gpib.kicad_sch, gpib_controller.kicad_pcb, microcontroller.kicad_sch]
2026-03-25 Fix GPIB DIO bus nets and start PCB. Adjusted to 4 layers
    [connectors.kicad_sch, gpib.kicad_sch, gpib_controller.kicad_pcb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]
2026-03-25 Adjust board size
    [gpib_controller.kicad_pcb]
2026-03-26 Fix page numbers and finish clock layout
    [gpib_controller.kicad_pcb, gpib_controller.kicad_sch, microcontroller.kicad_sch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]
2026-03-27 Route GPIB pins
    [gpib_controller.kicad_pcb, gpib_controller.kicad_sch]
2026-03-27 Change board size, complete bottom routing, update (still broken) jobfile
    [board_layout.dxf, gpib_controller.kicad_pcb, gpib_controller.kicad_sch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]
2026-03-27 Update microcontroller pinouts and finished routing of DIO1-4
    [gpib_controller.kicad_pcb, microcontroller.kicad_sch]
2026-03-27 Routing progress
    [gpib.kicad_sch, gpib_controller.kicad_pcb, microcontroller.kicad_sch]
2026-03-27 Final touches
    [gpib.kicad_sch, gpib_controller.kicad_pcb, microcontroller.kicad_sch]
2026-03-27 PCB finished, prior to rename and graphics
    [gpib_controller.kicad_pcb]
2026-03-27 LINCs the name.
    [gpib_controller.kicad_pcb]
2026-03-28 Update name
    [connectors.kicad_sch, gpib.kicad_sch, gpib_controller.kicad_pcb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]
2026-03-28 Add gerber .zip to gitignore
2026-03-28 Add gerber files
    [LINC-B_Cu.gbl, LINC-B_Mask.gbs, LINC-B_Paste.gbp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]
2026-03-28 chore: latest gerber files
    [LINC-B_Cu.gbl, LINC-B_Mask.gbs, LINC-B_Paste.gbp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]
2026-03-28 Migrate to outputs folder
    [LINC-B_Cu.gbl, LINC-B_Mask.gbs, LINC-B_Paste.gbp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]
2026-03-28 Add graphics
    [Linc_Logo.dxf]
2026-03-28 Add logo to PCB
    [LINC.kicad_pcb, Linc_Outline.dxf]
2026-03-28 Update graphics and license
    [LINC.kicad_pcb, LINC.kicad_sch]
2026-03-28 chore: generate new outputs
    [LINC-B_Cu.gbl, LINC-B_Mask.gbs, LINC-B_Paste.gbp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]
2026-03-28 Ready for release
    [LINC.kicad_pcb, microcontroller.kicad_sch]
2026-03-28 Final release, update logo
    [LINC-B_Cu.gbl, LINC-B_Mask.gbs, LINC-B_Paste.gbp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]
2026-05-30 Add outputs
    [.step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]
2026-06-02 Migrate to LDO for 3V3
    [LINC.kicad_pcb, microcontroller.kicad_sch, overview.kicad_sch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]
2026-06-02 Update STM32 symbol
    [LINC.kicad_pcb, microcontroller.kicad_sch]
2026-06-02 Implement SWO async tracing
    [LINC.kicad_pcb, microcontroller.kicad_sch]
2026-06-03 Change PWR LED to 1k current limiting
    [LINC.kicad_pcb, microcontroller.kicad_sch, transciever.kicad_sch]
2026-06-04 Update layout
    [LINC.kicad_pcb]
2026-06-04 Add and layout LED
    [LINC.kicad_pcb, microcontroller.kicad_sch]
2026-06-04 Bump gfx to 0.20
    [LINC.kicad_pcb, Linc_Logo.dxf, Linc_Outline.dxf]
2026-06-04 Update resistor pack
    [LINC.kicad_pcb, gpib.kicad_sch]
2026-06-04 Update outputs
    [LINC-B_Cu.gbl, LINC-B_Mask.gbs, LINC-B_Paste.gbp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]
2026-06-04 Add ground plane to bottom layer
    [LINC-B_Cu.gbl, LINC-B_Mask.gbs, LINC-B_Paste.gbp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]
2026-06-04 BOM Reduction
    [LINC.kicad_pcb, microcontroller.kicad_sch, transciever.kicad_sch]
2026-06-04 Update outputs to match BOM reduction
    [LINC-B_Cu.gbl, LINC-B_Mask.gbs, LINC-B_Paste.gbp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]
2026-06-05 Final v0.2.0
    [LINC-B_Cu.gbl, LINC-B_Mask.gbs, LINC-B_Paste.gbp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]
